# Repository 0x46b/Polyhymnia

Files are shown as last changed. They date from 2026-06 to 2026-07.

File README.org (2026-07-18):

#+TODO: TODO WIP VERIFY | DONE CANCELED

* Polyhymnia - Hybrid Synthesizer
Polyhymnia is an experimental hybrid-synthesizer. It is planned to use an Teensy 4.1 as oscillators and envelope-generator but using analogue filters.

Since I'll try to develop it myself version 1 will be completely digital, adding the analogue stuff incrementally as the project evolves.

WARNING:
Everything here is currenty under heavy development, so use at your own risk. Every code and schematics could and will change over time without warning ;)

[[https://github.com/0x46b/Polyhymnia/actions/workflows/polyhymnia_ci_build.yml/badge.svg]] [[https://github.com/0x46b/Polyhymnia/actions/workflows/encoder_ci_tests.yml/badge.svg]] [[https://github.com/0x46b/Polyhymnia/actions/workflows/polyhymnia_ci_tests.yml/badge.svg]]

* Vision
- digitally created oscillators using the Teensy 4.1
- using hardware parts for quick access for the most needed settings, like OSC-tuning, ADSR etc.
- TFT/LCD-Display for saving/loading patches
- full MIDI-IO
- saveable patches
- effect-section (delay, reverb, ...)
- totally standalone, but with MIDI-controllability (USB or DIN)
- onboard speaker as "emergency output" (quality will be shit, but nice enough to fiddle at patches, I guess)
- Case: Case for holding the synth with a little place for placing an MPK mini Plus as keys (could get connected via MIDI-cable then)

* Milestones
** WIP Software [0/3]
  - [-] SPI communication
  - [-] Design UI
  - Features [0/4]
    - [ ] Add code for LFO
    - [X] Saving/Loading settings to/from SD-card
    - [X] Saving/Loading patches to/from SD-card
    - [ ] Add effects (Reverb, Delay, BitCrush, ...)
** WIP Hardware [1/3]
  - [X] Build MIDI-port
  - [X] Display control
    - [X] Find working pinout/connection 
  - [-] Build Oscillator control modules [1/6]
    - [X] OSC 1
    - [ ] OSC 2
    - [ ] OSC 3
    - [ ] Build Status-LED-Driver module
    - [ ] Build Envelope control module
    - [ ] Build Filter control module

** TODO Enclosure [0/2]
    - [-] Design Enclosure
    - [ ] Build Enclosure

** TODO Documentation [0/1]
    - [ ] Update parts list

* Plan for Version 0.1 [1/5]
- [X] playable (controlled via Pure Data "software-UI" with pass-thru MIDI-Controller-Keyboard) via USB-Midi
- [X] 3 detunable VCOs with selectable waveforms (Saw, Triangle, Sine, Square)
- [X] controllable ladder-Lopass-filter
- [ ] controllable LFO for automating filter
- [X] controllable ADSR-Envelope
  
* Ideas for later
- Onboard-Sequencer
- Oscilloscope for showing the generated wave-form
* Documentation
** Used Libraries
- [[https://www.pjrc.com/teensy/td_libs_Audio.html][Teensy Audio Library]]
- [[https://github.com/vindar/ILI9341_T4][ILI9341_T4 Library]]
- [[https://github.com/bblanchon/ArduinoJson][ArduinoJson]]
- [[https://lvgl.io/][LVGL]]

** Used Software
- [[https://puredata.info/][Pure Data]]
- [[https://kicad.org/][KiCad]]
- [[https://www.freecadweb.org/][FreeCAD]]
- [[https://www.pjrc.com/teensy/teensyduino.html][Teensyduino]]
- [[https://www.envox.eu/studio/studio-introduction/][EEZ Studio]]
- [[https://www.doxygen.nl/][Doxygen]]
- [[https://platformio.org/][platformio]]
- [[https://vscodium.com/][VSCodium]]

** MIDI-CC
| CC value | Waveform |
|----------+----------|
|        0 | Sawtooth |
|        1 | Triangle |
|        2 | Square   |
|        3 | Sine     |

| CC value | Filter Type |
|----------+-------------|
|        0 | Low Pass    |
|        1 | High Pass   |
|        2 | Band Pass   |

| CC# | Function     |
|-----+--------------|
|  70 | VCO1 Type    |
|  76 | VCO1 Detune  |
|  77 | VCO2 Type    |
|  78 | VCO2 Detune  |
|  85 | VCO3 Type    |
|  86 | VCO3 Detune  |
|-----+--------------|
|  73 | Attack       |
|  80 | Decay        |
|  75 | Sustain      |
|  72 | Release      |
|-----+--------------|
|  74 | Cutoff       |
|  71 | Resonance    |
|  89 | Filtertype   |
|-----+--------------|
| 105 | LFO Rate     |
| 106 | LFO Amount   |
|-----+--------------|
| 20  | VCO1 Volume  |
| 21  | VCO2 Volume  |
| 22  | VCO3 Volume  |
| 23  | Noise Volume |
| 24  | Total Volume |

* Hardware
** Parts list [12/16]
- [X] Teensy 4.1
- [X] Teensy Audio Shield
- [X] 2x Buchsenleisten 1x24
- [X] 10x Rotary Encoder (ALPS?)
- [X] 4x8 LEDs (rot)
- [X] 4x Linear-Potentiometer (motorised?)
- [ ] 4x 74HC595 Shift-Registers
- [ ] 1x momentary switch (closed)
- [X] 2x Optokoppler 6N138
- [X] 2x DIN-Buchse 5-polig
- [ ] 1x CR2032 Halter
- [ ] 1x Audiobuchse 6.5mm
- [X] 1x ILI9341 Color TFT
- [X] 220 Ohm Resistor
- [X] 470 Ohm Resistor
- [X] 12 Red LED
  
** Audio-Amplifier (everything x2 if you want stereo):
- [X] LM386 Audio-Amplifier IC 
- [X] ElKo 250&micro;F
- [X] CerKo 33nF [333]
- [X] CerKo 50nF (alternative 47nF [473]
- [X] Resistor 10k&Omega;
- [X] Resistor 10&Omega;
- [X] Potentiometer 10k&Omega;

Power Supply:
- [ ] LM7805 Voltage Regulator
- [ ] 100uF Cap
- [ ] 10uF Cap
- [ ] 1N4001 Diode
- [ ] DC-Input-Jack
  
* Schematics
[[./Schematics/img/Main.png][Main Schematics]]
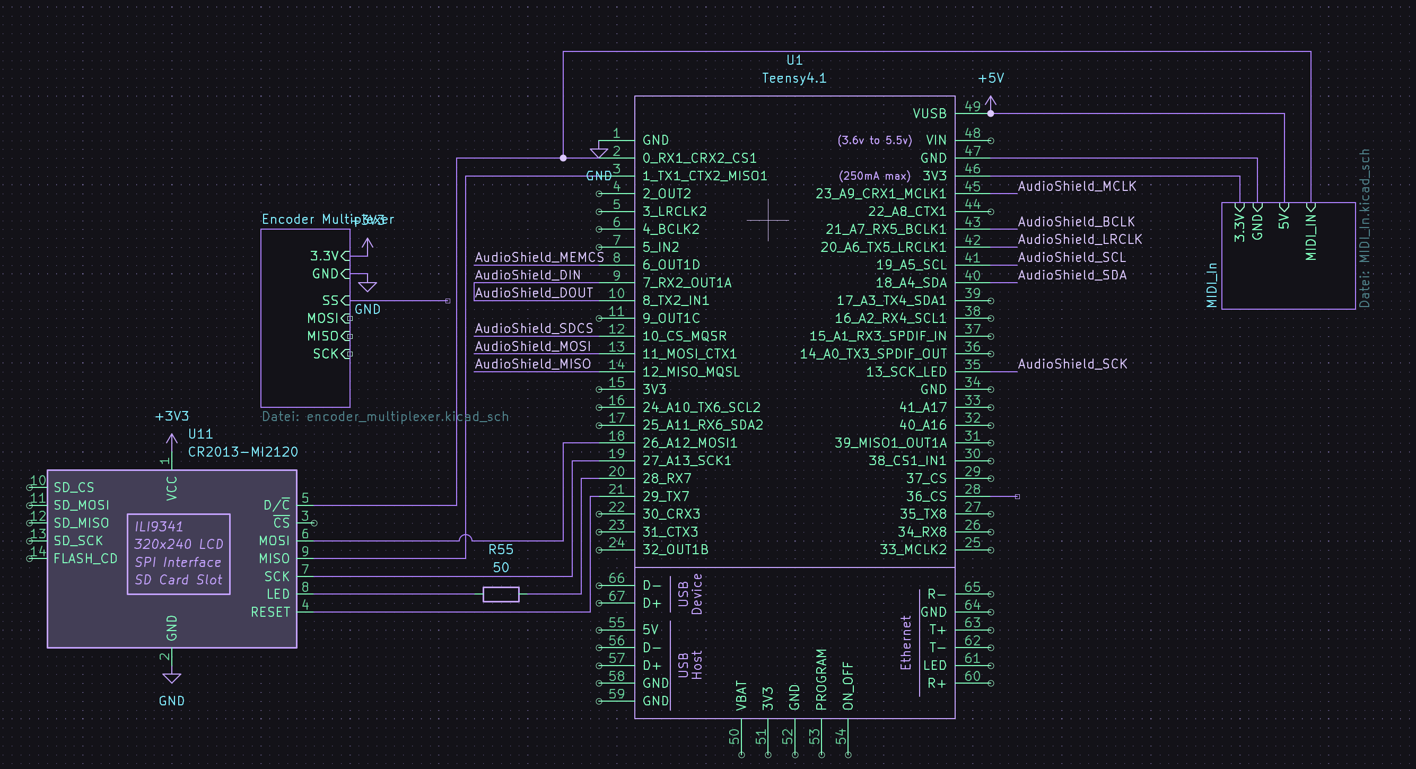
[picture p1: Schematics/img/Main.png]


[[./Schematics/img/Encoder_Control.png][Control Unit Schematics]]
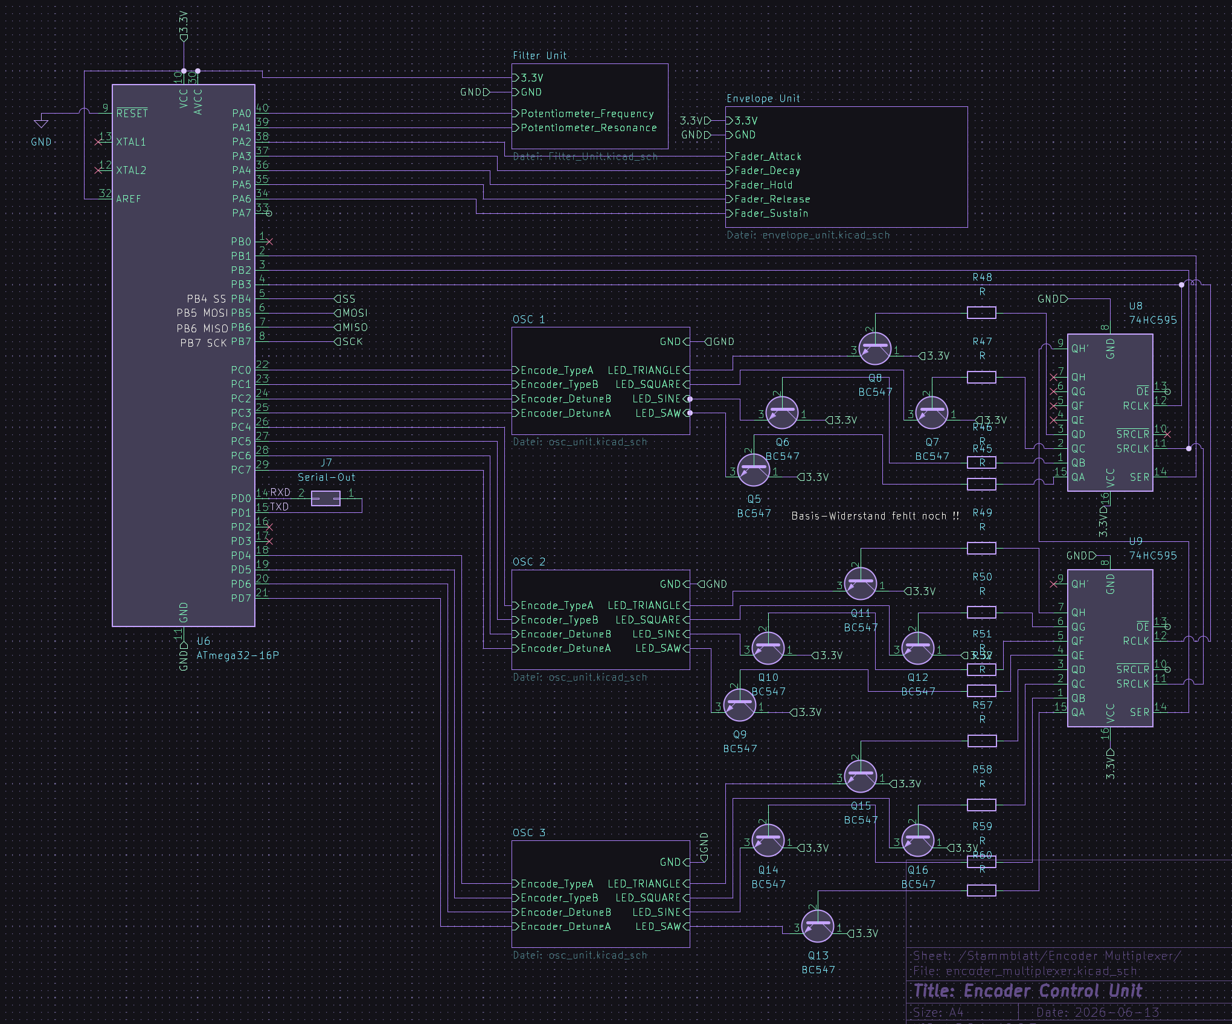
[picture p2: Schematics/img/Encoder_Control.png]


[[./Schematics/img/MIDI_In_Unit.png][MIDI In Schematics]]
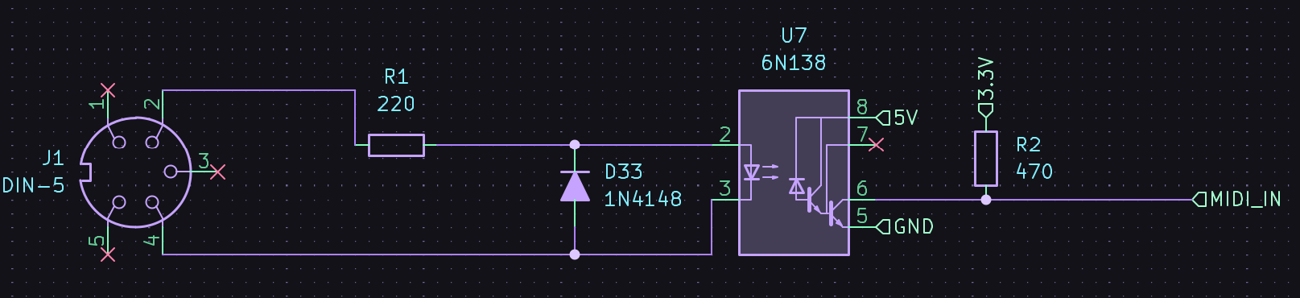
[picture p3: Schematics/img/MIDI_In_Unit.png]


[[./Schematics/img/OSC_Unit.png][OSC Control Unit Schematics]]
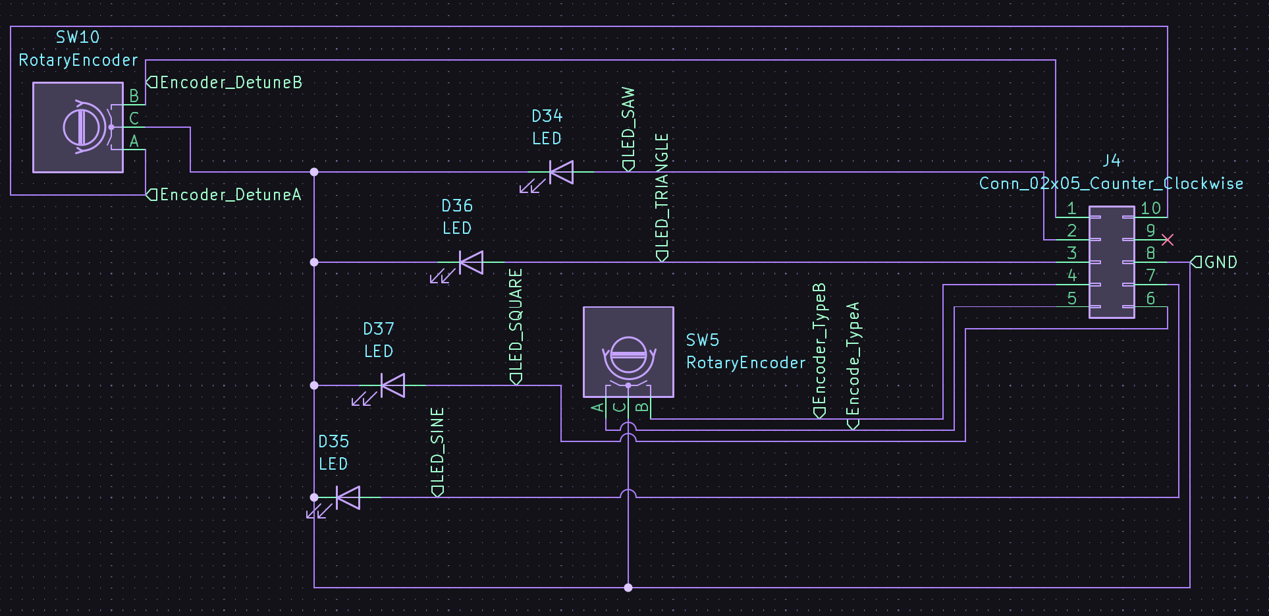
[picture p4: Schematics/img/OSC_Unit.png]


[[./Schematics/img/Filter_Unit.png][Filter Control Unit Schematics]]
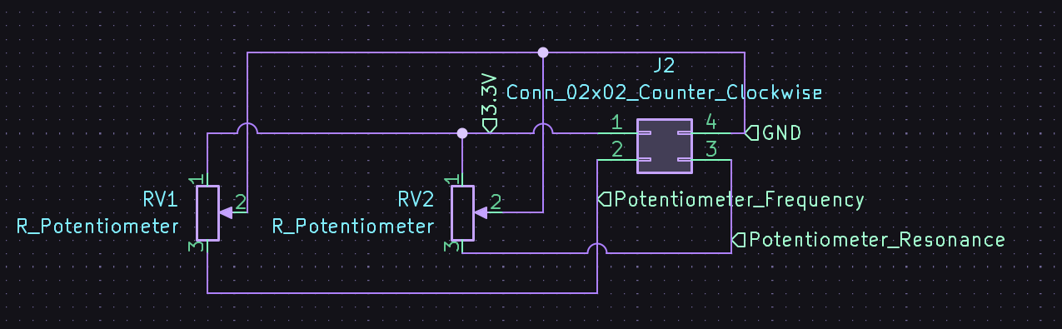
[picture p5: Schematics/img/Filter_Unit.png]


[[./Schematics/img/Envelope_Unit.png][Envelope Control Unit Schematics]]


[[./Schematics/img/audio_amp.png][LM386 Audio Amp Schematics (Mono)]]
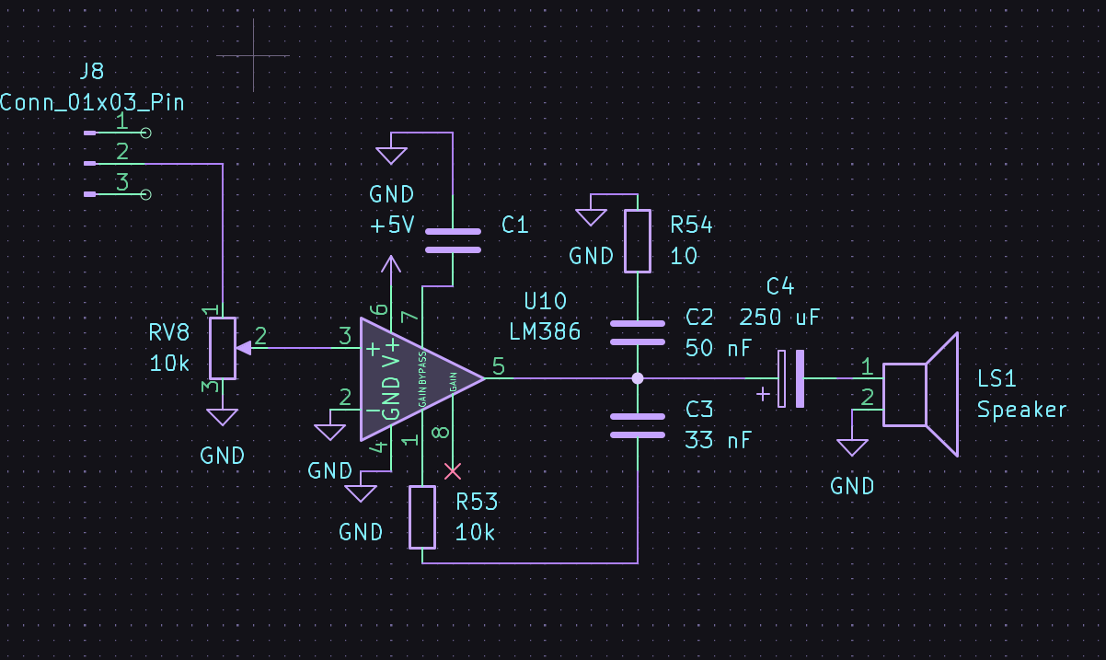
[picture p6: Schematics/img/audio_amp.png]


* Enclosure
[[./Enclosure/imgs/3d.png][3D rendering]]
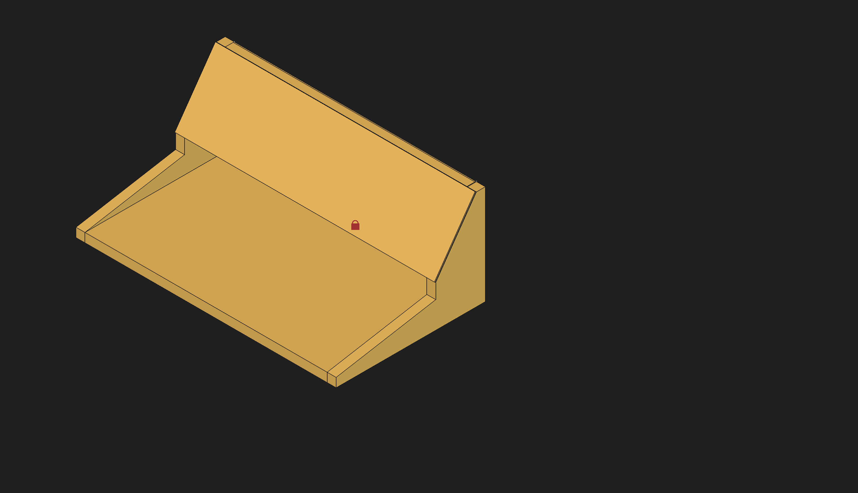
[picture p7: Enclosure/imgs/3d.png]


[[./Enclosure/imgs/Explosion.png][Explosion View]]
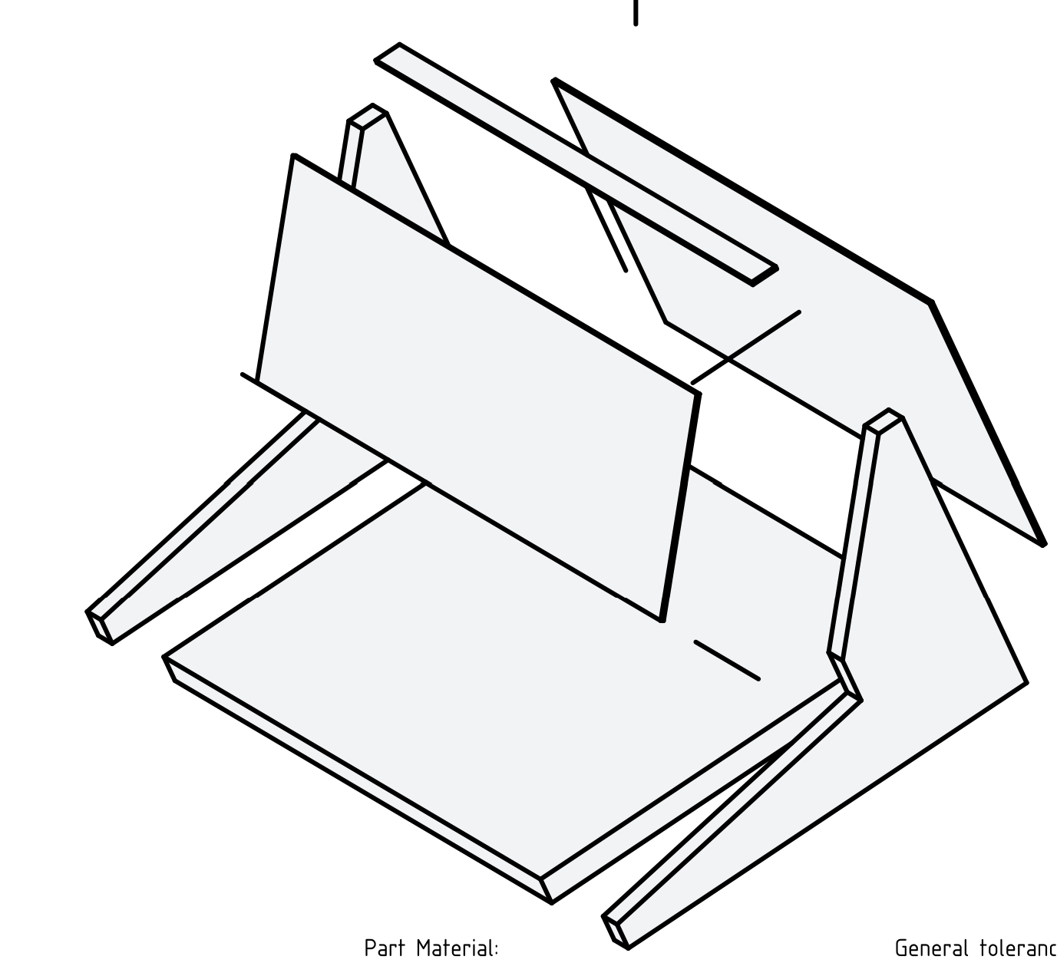
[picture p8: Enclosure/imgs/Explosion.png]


[[./Enclosure/imgs/right.png][Right Side View]]
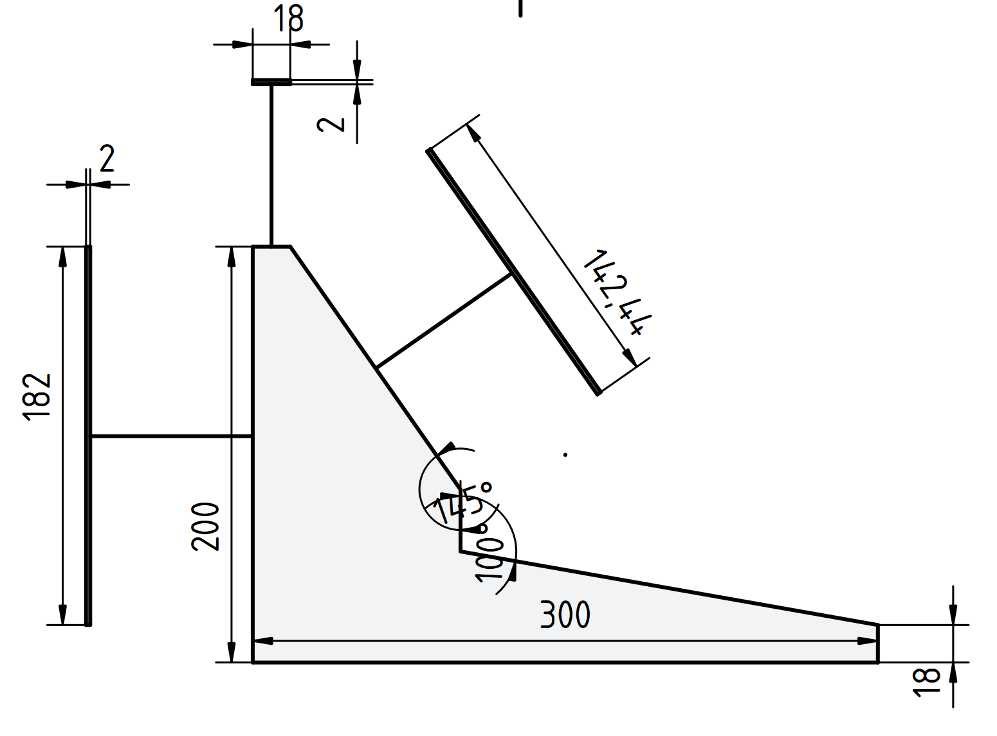
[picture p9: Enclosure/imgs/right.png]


[[./Enclosure/imgs/front.png][Front View]]
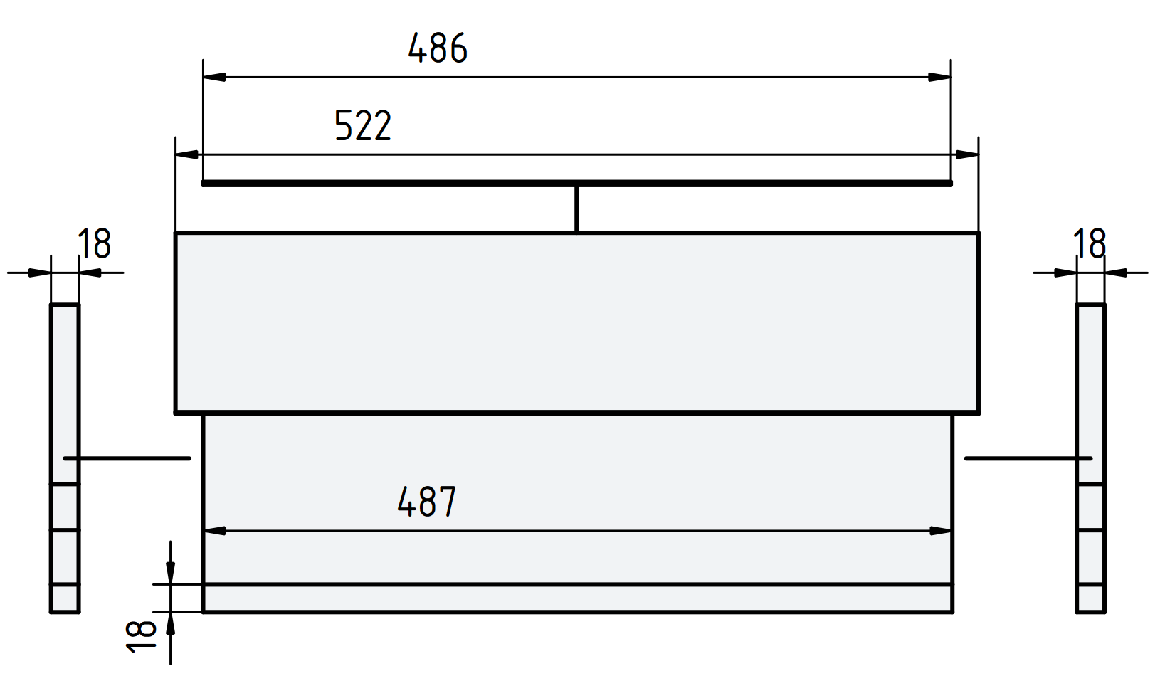
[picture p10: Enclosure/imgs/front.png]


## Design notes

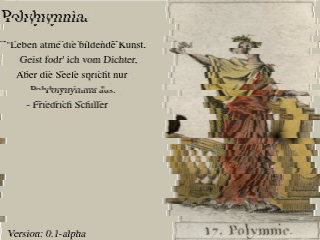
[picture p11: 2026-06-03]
Graphics/Bootup_Screen_distorted.bmp

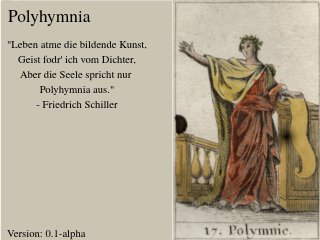
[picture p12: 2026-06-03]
Graphics/Bootup_Screen.jpg

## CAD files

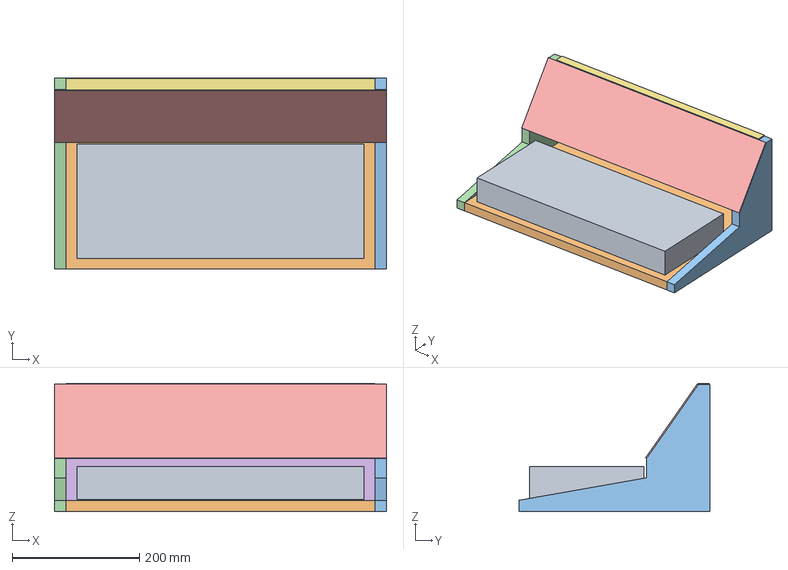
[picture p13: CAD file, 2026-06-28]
Enclosure/Enclosure.FCStd
522.0 x 300.3 x 202.0 mm
Akai Dummy
Base
Side R
Side L
Panel
Back-Panel
Top

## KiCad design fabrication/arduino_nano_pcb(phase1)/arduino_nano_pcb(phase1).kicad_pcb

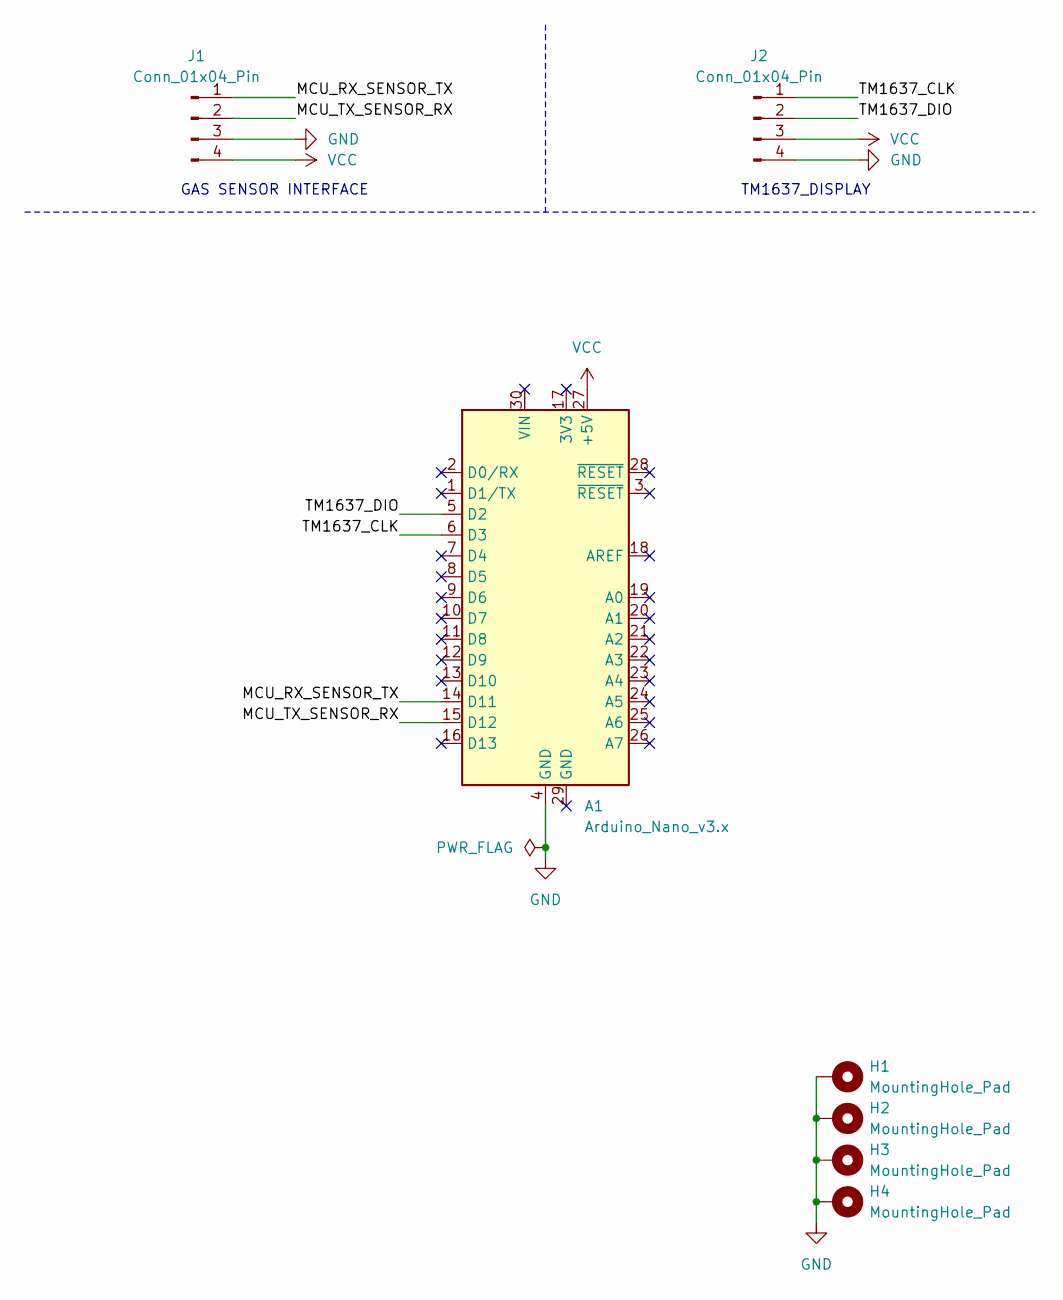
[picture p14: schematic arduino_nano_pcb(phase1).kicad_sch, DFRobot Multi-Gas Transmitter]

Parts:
A1: Arduino_Nano_v3.x; Arduino_Nano
H1, H2, H3, H4: MountingHole_Pad; MountingHole_5mm_Pad_TopBottom
J1: Conn_01x04_Pin; PinHeader_1x04_P2.54mm_Horizontal
J2: Conn_01x04_Pin; TM1637

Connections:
/MCU_RX_SENSOR_TX: A1.14 (D11), J1.1
/MCU_TX_SENSOR_RX: A1.15 (D12), J1.2
/TM1637_CLK: A1.6 (D3), J2.1
/TM1637_DIO: A1.5 (D2), J2.2
GND: A1.4 (GND), H1.1 (1_1), H2.1 (1_1), H3.1 (1_1), H4.1 (1_1), J1.3, J2.4
VCC: A1.27 (+5V), J1.4, J2.3

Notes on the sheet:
TM1637_DISPLAY
GAS SENSOR INTERFACE

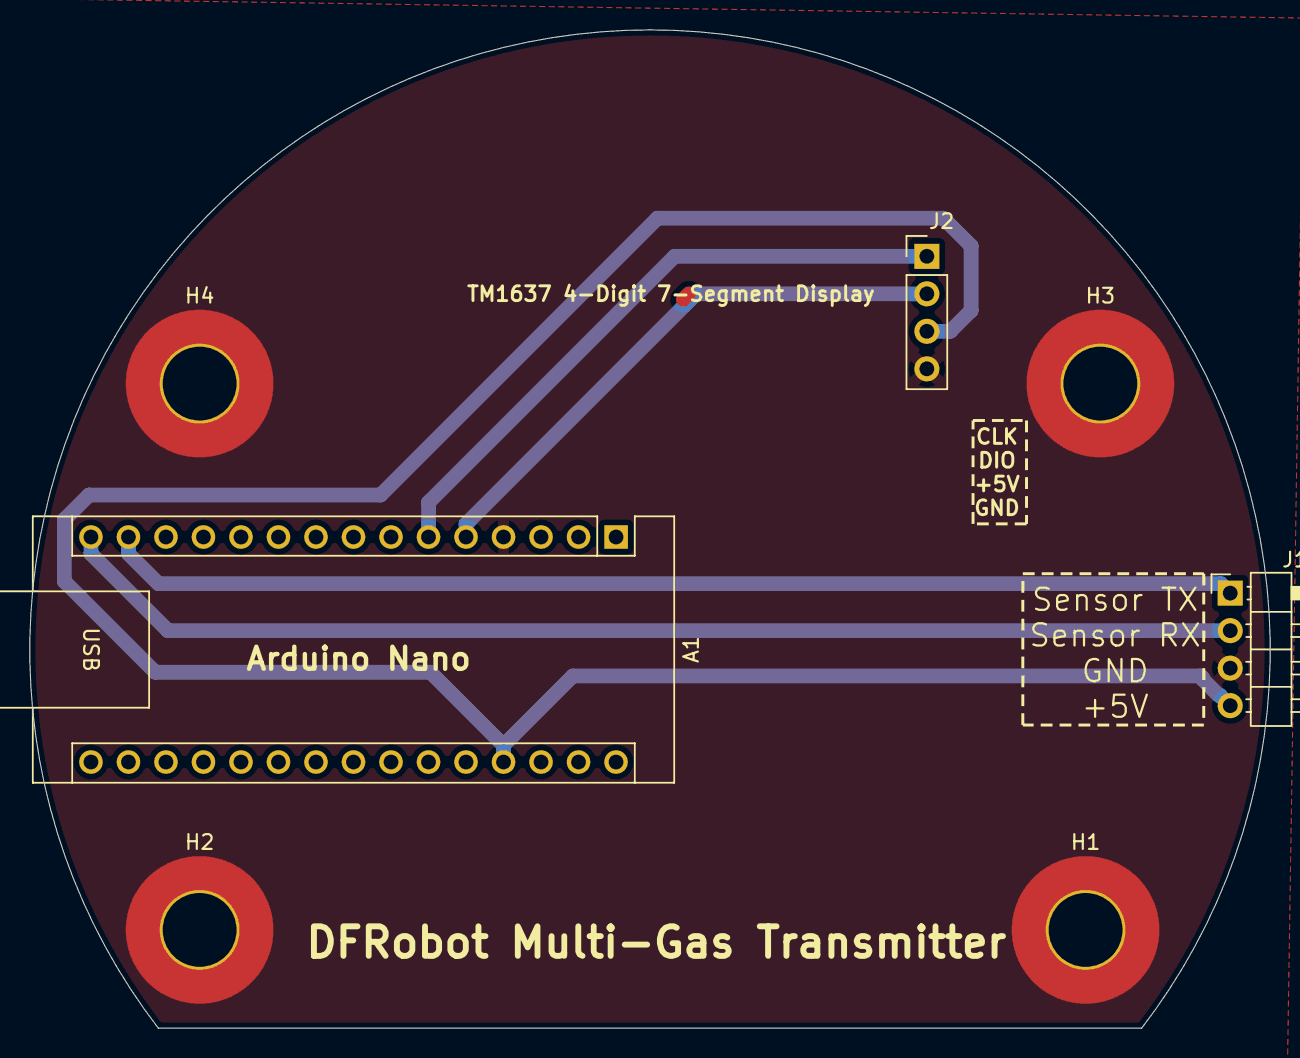
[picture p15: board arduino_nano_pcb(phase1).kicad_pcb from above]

Board: 2 copper layers, 84.0 x 67.6 mm, 7 parts (0 on the bottom side), 6 nets.

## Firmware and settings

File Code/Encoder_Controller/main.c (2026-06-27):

#include <avr/interrupt.h>
#include <avr/io.h>
#include <avr/pgmspace.h>
#include <stdlib.h>

#include <util/delay.h>

#include "control_types.h"
#include "encoder.h"
#include "fader.h"
#include "ringbuffer.h"
#include "serial.h"
#include "spi_handler.h"

#include <assert.h>

#define XTAL 8e6

oscillator_controller oscillator_controllers[3];
envelope_controller adsr_controller;
filter_controller lowpass_controller;

void print_encoder_to_serial(encoder_config encoder) {
  char buffer[10];
  serial_send_string("Encoder ", false);
  serial_send_string(buffer, false);
  serial_send_string(": {", false);
  itoa(encoder.offset, buffer, 10);
  serial_send_string(buffer, false);
  serial_send(',', false);
  itoa(encoder.oldState, buffer, 10);
  serial_send_string(buffer, false);
  serial_send(',', false);
  itoa(encoder.pinA, buffer, 2);
  serial_send_string(buffer, false);
  serial_send(',', false);
  itoa(encoder.pinB, buffer, 2);
  serial_send_string(buffer, false);

  serial_send('}', true);
}

ISR(TIMER0_COMP_vect) {
  for (int i = 0; i < 3; i++) {
    oscillator_tick(&oscillator_controllers[i]);
  }
}

ISR(SPI_STC_vect) { handle_received_byte(SPDR); }

void initialize_encoder_timer(void) { // nur Timer 0 initialisieren
  TCCR0 = (1 << WGM01) | (1 << CS01) | (1 << CS00); // CTC, prescaler 64
  OCR0 = (uint8_t)(F_CPU / 64.0 * 1e-3 - 0.5);      // 1ms
  TIMSK |= 1 << OCIE0;
}

void leds_initialize(oscillator_type_LED_config *ledConfig) {
  assert(!"The method or operation is not implemented.");
}

void initialize_oscillator_controller(oscillator_controller *oscillator,
                                      uint8_t id) {
  oscillator->state.Id = id;
  oscillator->state.DetuneOffset = 0;
  oscillator->state.Type = SAW;
}

void setup(void) {
  serial_initialize();
  serial_send_string("Initializing Ports...", true);
  // OSC1
  initialize_oscillator_controller(&oscillator_controllers[0], 0);
  // Type encoder
  encoder_initialize(&oscillator_controllers[0].encoderType, &PINC, &DDRC,
                     &PORTC, PC0, PC1);
  // Detune encoder
  encoder_initialize(&oscillator_controllers[0].encoderDetune, &PINC, &DDRC,
                     &PORTC, PC2, PC3);
  leds_initialize(&oscillator_controllers[0].ledConfig);

  // OSC2
  initialize_oscillator_controller(&oscillator_controllers[1], 1);
  // OSC2 Type
  encoder_initialize(&oscillator_controllers[1].encoderType, &PINC, &DDRC,
                     &PORTC, PC4, PC5);
  // OSC2 Detune
  encoder_initialize(&oscillator_controllers[1].encoderDetune, &PINC, &DDRC,
                     &PORTC, PC6, PC7);
  leds_initialize(&oscillator_controllers[1].ledConfig);

  // OSC3
  initialize_oscillator_controller(&oscillator_controllers[2], 2);
  // OSC3 Type (PD0 + PD1 are used for debugging output via serial)
  encoder_initialize(&oscillator_controllers[2].encoderType, &PIND, &DDRD,
                     &PORTD, PD2, PD3);
  // OSC3 Detune
  encoder_initialize(&oscillator_controllers[2].encoderType, &PIND, &DDRD,
                     &PORTD, PD4, PD5);
  leds_initialize(&oscillator_controllers[2].ledConfig);

  // ADSR
  envelope_initialize(&adsr_controller, 0, 1, 2, 3);

  // LowPass
  filter_initialize(&lowpass_controller, 4, 5);

  serial_send_string("Starting timer...", true);
  initialize_encoder_timer();
  initialize_spi();
}

void put_envelope_data_into_transfer_buffer(void) {
  update_envelope_state(&adsr_controller);
  buffer_write(&_transferBuffer, adsr_controller.state.Attack);
  buffer_write(&_transferBuffer, adsr_controller.state.Decay);
  buffer_write(&_transferBuffer, adsr_controller.state.Sustain);
  buffer_write(&_transferBuffer, adsr_controller.state.Release);
  _transfer_length_in_bytes = ReadEnvelopeLen;
}

void put_filter_data_into_transfer_buffer(void) {
  update_filter_state(&lowpass_controller);
  buffer_write(&_transferBuffer, lowpass_controller.state.Cutoff);
  buffer_write(&_transferBuffer, lowpass_controller.state.Resonance);
  _transfer_length_in_bytes = ReadFilterLen;
}

void put_lfo_data_into_transfer_buffer(void) {
  assert(!"The method or operation is not implemented.");
}

void put_osc_data_into_transfer_buffer(uint8_t id) {
  buffer_write(&_transferBuffer, oscillator_controllers[id].state.Id);
  buffer_write(&_transferBuffer, oscillator_controllers[id].state.DetuneOffset);
  buffer_write(&_transferBuffer, oscillator_controllers[id].state.Type);
  _transfer_length_in_bytes = ReadOSCLen;
}

void set_waveform_for_osc(OscillatorType type, uint8_t id) {
  oscillator_controller *controller = &oscillator_controllers[id];
  switch (type) {
  case SAW:
    *controller->ledConfig.pin |= (1 << controller->ledConfig.pinSaw);
    *controller->ledConfig.pin &= ~(1 << controller->ledConfig.pinSine) |
                                  ~(1 << controller->ledConfig.pinTriangle) |
                                  ~(1 << controller->ledConfig.pinSquare);
    break;
  case TRIANGLE:
    *controller->ledConfig.pin |= (1 << controller->ledConfig.pinTriangle);
    *controller->ledConfig.pin &= ~(1 << controller->ledConfig.pinSine) |
                                  ~(1 << controller->ledConfig.pinSaw) |
                                  ~(1 << controller->ledConfig.pinSquare);
    break;
  case SINE:
    *controller->ledConfig.pin |= (1 << controller->ledConfig.pinSine);
    *controller->ledConfig.pin &= ~(1 << controller->ledConfig.pinSaw) |
                                  ~(1 << controller->ledConfig.pinTriangle) |
                                  ~(1 << controller->ledConfig.pinSquare);
    break;
  case SQUARE:
    *controller->ledConfig.pin |= (1u << controller->ledConfig.pinSquare);
    *controller->ledConfig.pin &= ~(1u << controller->ledConfig.pinSine) |
                                  ~(1u << controller->ledConfig.pinTriangle) |
                                  ~(1u << controller->ledConfig.pinSaw);
    break;
  }
  controller->state.Type = type;
}

void handle_spi_commands(void) {
  if (_spi_state == CMD_EXEC) {
    switch (_lastCommand.command) {
    case ReadEnvelope:
      put_envelope_data_into_transfer_buffer();
      _spi_state = TRANSFER_READY;
      break;
    case ReadFilter:
      put_filter_data_into_transfer_buffer();
      _spi_state = TRANSFER_READY;
      break;
    case ReadLFO:
      put_lfo_data_into_transfer_buffer();
      _spi_state = TRANSFER_READY;
      break;
    case ReadOSC:
      put_osc_data_into_transfer_buffer(_lastCommand.payload);
      _spi_state = TRANSFER_READY;
      break;
    case SetWaveformSaw:
      set_waveform_for_osc(SAW, _lastCommand.payload);
      _spi_state = CMD_READ;
      break;
    case SetWaveformSine:
      set_waveform_for_osc(SINE, _lastCommand.payload);
      _spi_state = CMD_READ;
      break;
    case SetWaveformSquare:
      set_waveform_for_osc(SQUARE, _lastCommand.payload);
      _spi_state = CMD_READ;
      break;
    case SetWaveformTriangle:
      set_waveform_for_osc(TRIANGLE, _lastCommand.payload);
      _spi_state = CMD_READ;
      break;
    default:
      _spi_state = UNKNOWN_COMMAND;
      break;
    case SetEnvelope:
      break;
    case SetLFO:
      break;
    case SetFilter:
      break;
    }
  }
}

int main(void) {
  setup();
  serial_send_string("Setup finished", true);
  sei();

  while (1) {
    handle_spi_commands();
  }
}

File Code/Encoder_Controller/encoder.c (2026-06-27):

#include "encoder.h"

void encoder_initialize(volatile encoder_config *config, volatile uint8_t *pin,
                        volatile uint8_t *ddr, volatile uint8_t *port,
                        uint8_t phaseA, uint8_t phaseB) {
  config->pinA = (1 << phaseA);
  config->pinB = (1 << phaseB);
  config->pin = pin;
  config->offset = 0;
  config->oldState = 0;

  *port |= config->pinA | config->pinB;
  *ddr &= ~config->pinA | ~config->pinB;
}

int encoder_read_offset(volatile encoder_config *encoder) {
  int8_t currentOffsetBuff = encoder->offset;
  encoder->offset = 0;

  return currentOffsetBuff;
}

void encoder_tick(volatile encoder_config *encoder) {
  // Shift old-state 2 to the right and trim first byte
  // e.g. old-state = 00001010 => <<2 => 00101000 => &0x0F => 00001000
  encoder->oldState = (encoder->oldState << 2) & 0x0F;
  // Check, if A is HIGH, if so set second last bit to 1
  if (*encoder->pin & encoder->pinA) {
    encoder->oldState |= 2;
  }
  // Check, if B is HIGH, if so set last bit to 1
  if (*encoder->pin & encoder->pinB) {
    encoder->oldState |= 1;
  }

  // Get value from our gray-table
  int8_t movement = STATETABLE[encoder->oldState];
  if (movement == 1 || movement == -1) {
    encoder->offset += movement;
  }
}

OscillatorType handle_type_change(int typeOffset) {
  assert(!"The method or operation is not implemented.");
}

void oscillator_tick(volatile oscillator_controller *controller) {
  encoder_tick(&controller->encoderDetune);
  encoder_tick(&controller->encoderType);
  controller->state.DetuneOffset +=
      encoder_read_offset(&controller->encoderDetune);
  controller->state.Type =
      handle_type_change(encoder_read_offset(&controller->encoderType));
}

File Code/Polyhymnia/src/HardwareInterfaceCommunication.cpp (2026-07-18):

#include "HardwareInterfaceCommunication.h"

HardwareInterfaceCommunication::HardwareInterfaceCommunication(){
}

void HardwareInterfaceCommunication::Initialize() {
  // _spiConnection->setMOSI(HW_INTERFACE_MOSI);
  // _spiConnection->setMISO(HW_INTERFACE_MISO);
  // _spiConnection->setSCK(HW_INTERFACE_SCK);
  // _spiConnection->setBitOrder(LSBFIRST);
  // _spiConnection->setDataMode(SPI_MODE0);
  // _spiConnection->setClockDivider(SPI_CLOCK_DIV128);
  _spiConnection->begin();
}

OscillatorState HardwareInterfaceCommunication::GetOscillatorState(uint8_t id) {
  SPI_Frame frame{
    ReadOSC,
    id
  };
  InitiateCommunication();
  SendFrame(frame);

  OscillatorState state;
  state.Id = ReceiveByte();
  Serial.print("Received id: ");
  Serial.print(state.Id);

  state.Offset = ReceiveByte();
  Serial.print("Received offset: ");
  Serial.print(state.Offset);
  
  state.Type = static_cast<OscillatorType>(ReceiveByte());
  Serial.print("Received type: ");
  Serial.print(state.Type);
  
  EndCommunication();
  return state;
}

void HardwareInterfaceCommunication::SetOscillatorWaveform(uint8_t id, OscillatorType type) {
  spi_command waveformCommand;

  switch (type) {
    case SAW:
      waveformCommand = SetWaveformSaw;
      break;
    case TRIANGLE:
      waveformCommand = SetWaveformTriangle;
      break;
    case SQUARE:
      waveformCommand = SetWaveformSquare;
      break;
    case SINE:
      waveformCommand = SetWaveformSine;
      break;
  };

  SPI_Frame frame{
    waveformCommand,
    id
  };
  InitiateCommunication();
  SendFrame(frame);
  EndCommunication();
}

EnvelopeState HardwareInterfaceCommunication::GetEnvelopeState() {
  SPI_Frame frame{
    ReadEnvelope,
    0
  };
  InitiateCommunication();
  SendFrame(frame);

  EnvelopeState state;
  state.Attack = ReceiveByte();
  state.Decay = ReceiveByte();
  state.Sustain = ReceiveByte();
  state.Release = ReceiveByte();
  EndCommunication();
  return state;
}

FilterState HardwareInterfaceCommunication::GetFilterState() {
  SPI_Frame frame{
    ReadFilter,
    0
  };
  InitiateCommunication();
    SendFrame(frame);

  FilterState state;
  state.Resonance = ReceiveByte();
  EndCommunication();
  return state;
}

LFOState HardwareInterfaceCommunication::GetLFOState() {
  SPI_Frame frame{
    ReadLFO,
    0
  };

  InitiateCommunication();

  SendFrame(frame);
  LFOState state;
  state.Frequency = ReceiveByte();
  state.Amount = ReceiveByte();

  EndCommunication();
  return state;
}

void HardwareInterfaceCommunication::InitiateCommunication() {
  Serial.println("Initializing com");
  _communicationActive = true;
  digitalWrite(HW_INTERFACE_SS, LOW);
}

void HardwareInterfaceCommunication::EndCommunication() {
  Serial.println("Ending com");
  _communicationActive = false;
  digitalWrite(HW_INTERFACE_SS, HIGH);
}

void HardwareInterfaceCommunication::SendByteWithStatusHandling(uint8_t byte) {
  uint8_t moduleState = SPI.transfer(byte);
  if (moduleState != MODULE_LISTENING) {
    switch (moduleState) {
      case MODULE_BUSY:
        Serial.println("Module busy");
        // TODO Do something, I dunno what ATM
        break;
      case MODULE_FAILURE:
        Serial.println("Module failure");
        // TODO Do something, I dunno what ATM
        break;
      default:
      Serial.print("Unknown response:");
      Serial.println(moduleState, HEX);
        // TODO Do something, I dunno what ATM
        break;
    }
  }
}

void HardwareInterfaceCommunication::SendFrame(SPI_Frame command) {
  Serial.print("Sending Frame: {");
  Serial.print(command.command, HEX);
  Serial.print(", ");
  Serial.print(command.payload, HEX);
  Serial.println("}");
  SendByteWithStatusHandling(command.command);
  SendByteWithStatusHandling(command.payload);
}

uint8_t HardwareInterfaceCommunication::ReceiveByte(){
  return SPI.transfer(0);
}

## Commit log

2026-06-01 Added first draft for ATMega32 encoder controller
2026-06-01 Added first draft for the schematics (WIP)
    [Polyhymnia.kicad_pcb, Polyhymnia.kicad_sch]
2026-06-01 Pulled parts into hierarchical schematics
    [LED-Matrix.kicad_sch, Polyhymnia.kicad_sch, audio_shield_dummy.kicad_sch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]
2026-06-04 Fixed encoder-reading and started adding SPI-communication
    [encoder.c]
2026-06-05 Added cpp class and program to be able to read multiple encoders per timer-interrupt
2026-06-05 Added first methods for SPI-handling
2026-06-05 Restructured code for encoder-controller
2026-06-05 Cleaned up wiring
    [Polyhymnia.kicad_sch, encoder_multiplexer.kicad_sch]
2026-06-05 Added second encoder for testing-purposes
2026-06-06 FINALLY fixed multiple encoder-reading
    [encoder.c, main.c]
2026-06-06 Readded other encoders and added setting DDR to encoder initialization
2026-06-06 Added MIDI in to schematics
    [MIDI_In.kicad_sch, Polyhymnia.kicad_sch]
2026-06-06 Added note to MIDI-In
    [MIDI_In.kicad_sch]
2026-06-07 Added schematics for filter, fader and envelope modules
    [Filter_Unit.kicad_sch, Polyhymnia.kicad_sch, envelope_unit.kicad_sch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]
2026-06-07 Added schematics for OSC, Filter and Envelope and updated README
    [Filter_Unit.kicad_sch, Polyhymnia.kicad_sch, encoder_multiplexer.kicad_sch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]
2026-06-07 Added Encoder Control Unit schematics and updated README
2026-06-11 Ported encoder-controller code back to C
2026-06-11 Updated schematics
    [encoder_multiplexer.kicad_sch, osc_unit.kicad_sch]
2026-06-13 Added audio amplifier schematics
    [Filter_Unit.kicad_sch, LED-Matrix.kicad_sch, MIDI_In.kicad_sch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]
2026-06-21 Added first draft for an enclosure
    [Enclosure.FCStd]
2026-06-25 Added SPI-Masterhandler
2026-06-27 Started implementing spi-logic
2026-06-27 Fixed compile-errors, restructured code and replaced Makefile
    [encoder.c, fader.c, main.c]
2026-06-30 Added CPPUTest as test-framework and first test
2026-07-18 Fixing the serial-logger and refactoring
    [SerialLogger.cpp]
